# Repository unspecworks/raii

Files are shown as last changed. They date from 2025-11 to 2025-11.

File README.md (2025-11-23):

> [!WARNING]
> work in progress

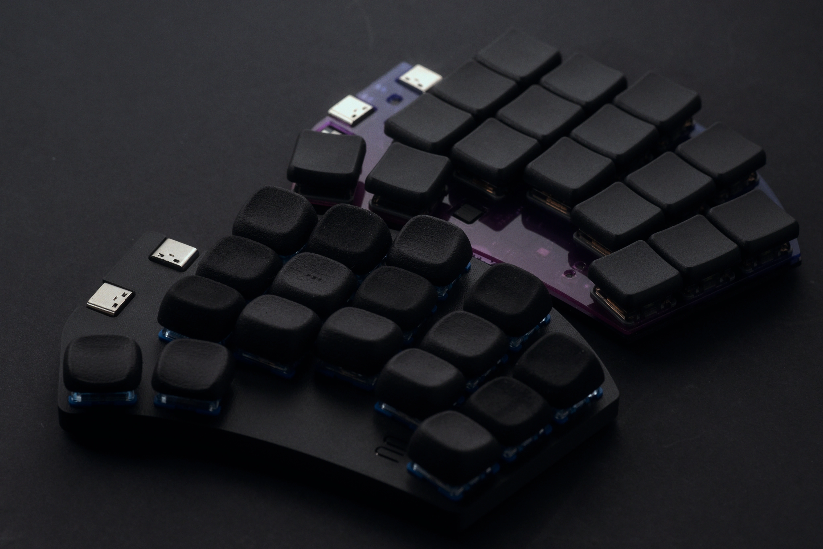
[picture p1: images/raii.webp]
RAII


# RAII

RAII is a customized variant of [waffle87/sweep](https://github.com/waffle87/sweep) featuring splayed columns and various PCB and footprint updates.

## Modifications

* Applied splay to the ring and pinky columns
* Added an additional BOOTSEL button footprint for alternative cases
* Removed the tenting puck mount
* Replaced solder-only switch footprints with Kailh hotswap ONLY sockets
* Added support for Kailh Choc V2
* Added cute ferris

## Links

* [/cases](./cases)
* [/pcb](./pcb)
* [/plate](./plate)
* [firmware](#)

## License

[SOLDERPAD HARDWARE LICENSE VERSION 2.1](./LICENSE)

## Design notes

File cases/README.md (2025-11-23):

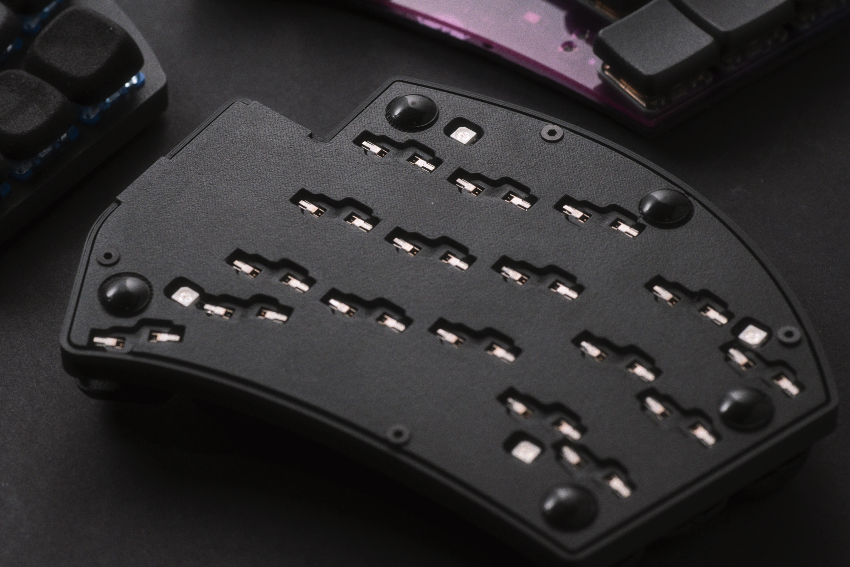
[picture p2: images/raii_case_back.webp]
Plate


# RAII Cases

All case variants use the same bottom case. Make sure to distinguish between the left and right sides.

It has only been tested with FDM printing and was designed specifically with FDM in mind.

## Recommended Version

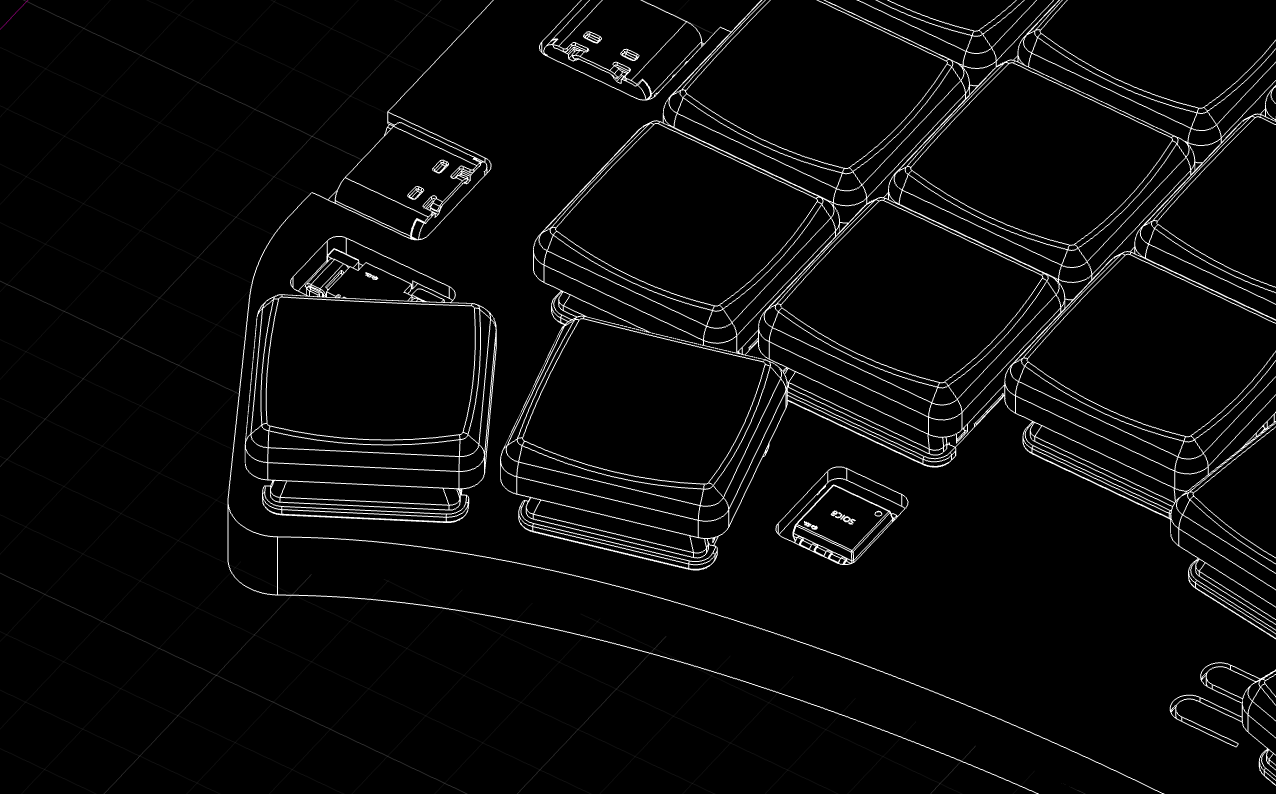
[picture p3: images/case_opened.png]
Opened


All PCB components are placed on the top side, but a few of them sit slightly lower than the height of the Kailh Choc switch plate's top face. Because of this, creating a perfectly enclosed top cover is challenging. Components such as the Flash memory and the display connector may still end up exposed.

- files: `top_left_opened.step` and `top_right_opened.step`

## Fully Enclosed Version

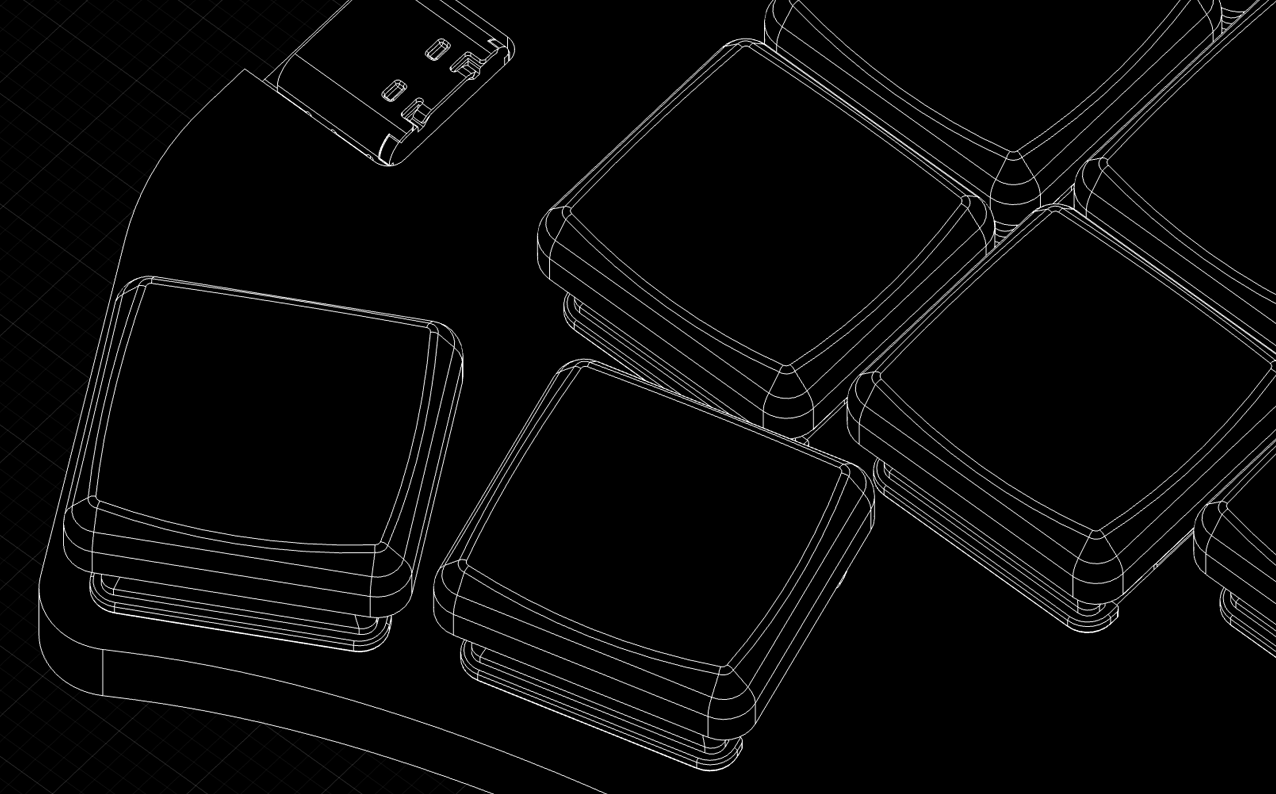
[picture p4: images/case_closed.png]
Closed


This version hides all components (excluding the USB-C receptacle) under a very thin wall. It is optimized for FDM printing.  
Due to the thinness and the nearly contacted height, the cover may bulge during assembly or when removing it from the build plate.

It is recommended to print at least two layers of 0.08 mm.

- files: `top_left_closed.step` and `top_right_closed.step`

## BOM for Assembly

- Rubber feets (≤ 9 mm Diameter), 10 pcs  
- M2 countersunk screws, 5 mm length, 8 pcs  

## Assembly Notes

Insert the switches into the case first, then attach the PCB afterward.  
(Verify switch pin orientation.)  
Attaching the switches and PCB together before inserting them may damage the thin case walls.

This case does not use threaded inserts. Screws are driven directly into the plastic.  
Do not overtighten the screws when assembling the case.

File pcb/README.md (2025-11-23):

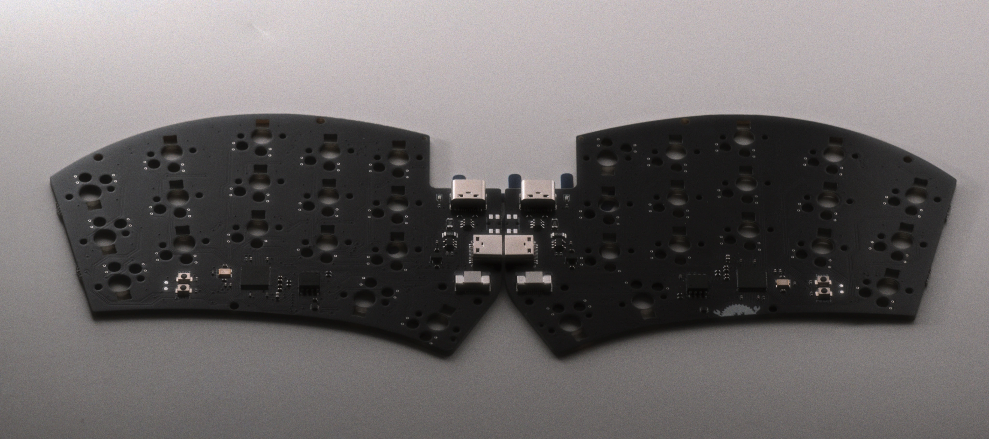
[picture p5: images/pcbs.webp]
PCB


# RAII PCB

## Ordering

TODO

## Hotswap Socket Orientation

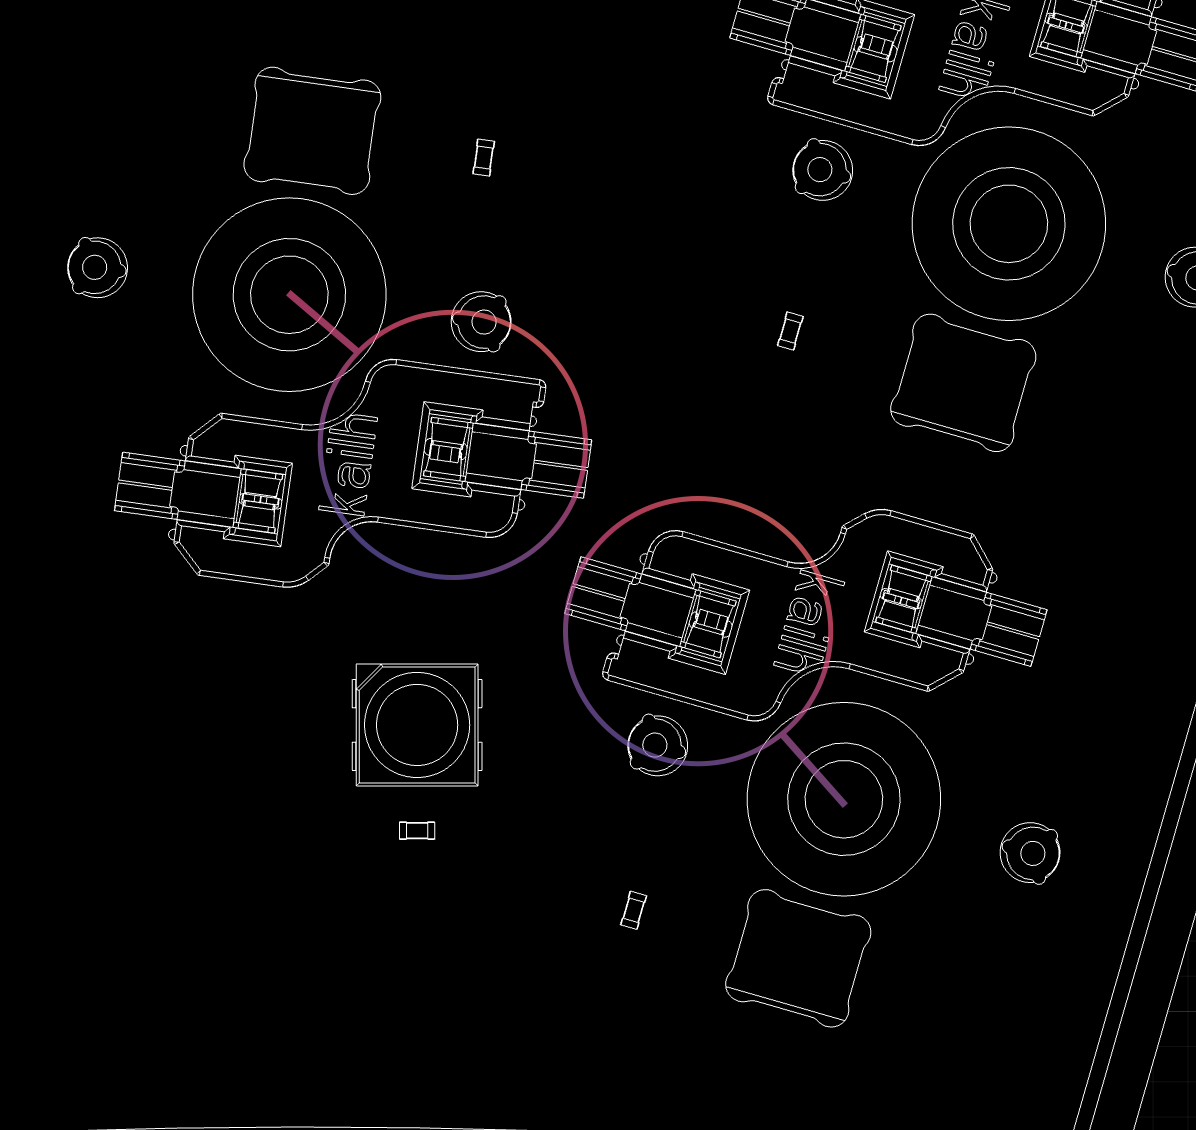
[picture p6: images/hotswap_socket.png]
Socket


If you plan to solder the hotswap sockets yourself, orient the socket so that the rectangular portion faces the center of the switch (the switch center hole).
This orientation is recommended for proper case compatibility.

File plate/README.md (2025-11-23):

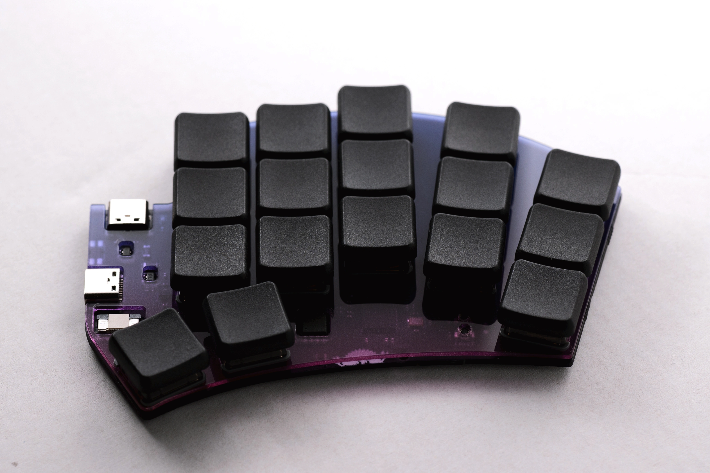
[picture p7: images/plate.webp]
Plate


# RAII Plate

Since this design relies on hotswap sockets, it is recommended to use a plate if you are not using a case.  
There are no standoffs, but the plate should still provide meaningful support.

Because plates are typically intended for flat CNC or laser cutting, some components will inevitably remain exposed.

## Notes

The recommended plate thickness for Choc switches is 1.2 mm.

## Gradient Tint?

Some acrylic fabrication services offer gradient-tinted coloring for cut parts.  
It is difficult to recommend a specific vendor, but platforms like Taobao often have various suppliers that provide this option.

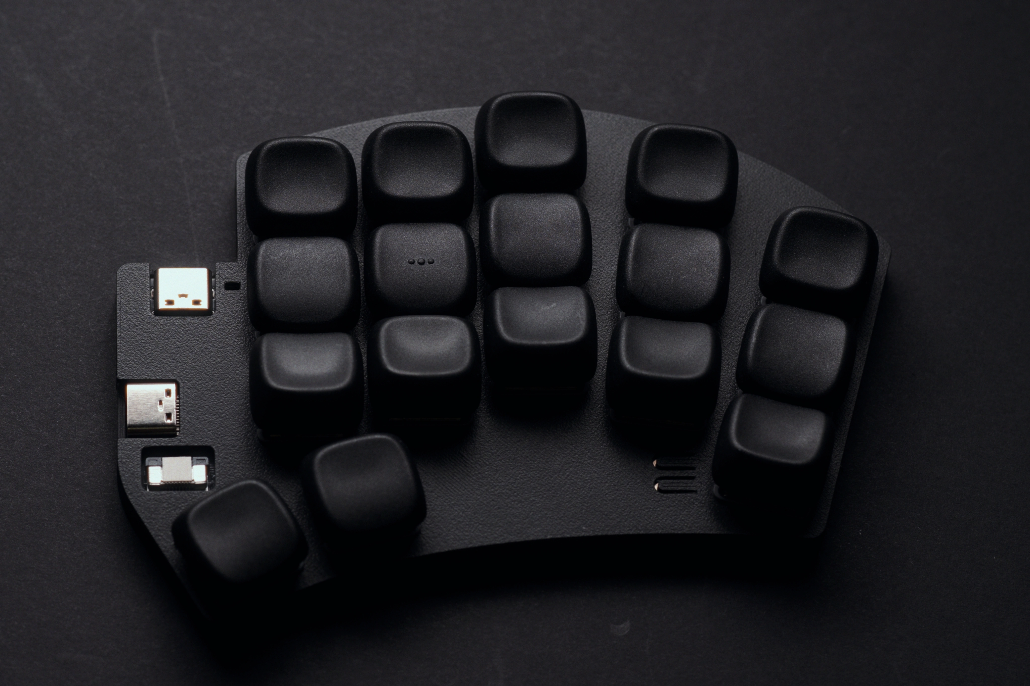
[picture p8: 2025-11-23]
images/f3.webp

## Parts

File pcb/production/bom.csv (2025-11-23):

Designator | Footprint | Quantity | Value | LCSC Part #
C1, C12, C13, C16, C2, C20, C23, C24, C4, C6 | 0402 | 10 | 1u | C52923
C10, C11, C21, C22 | 0402 | 4 | 22p | C1555
C14, C17, C18, C19, C25, C26, C27, C28, C29, C30, C31, C32, C33, C34, C35, C36, C37, C38, C39, C40, C41, C42, C43, C44, C45, C46, C47, C48, C49, C5, C50, C51, C52, C53, C54, C55, C56, C57, C58, C59, C60, C61, C62, C63, C64, C65, C66, C67, C68, C69, C7, C70, C71, C72, C73, C74, C75, C76, C8, C9 | 0402 | 60 | 100n | C1525
C15, C3 | 0603 | 2 | 10u | C19702
D1, D2 | 0603 | 2 | LED | C2286
D10, D3, D4, D5, D6, D7, D8, D9 | LED_WS2812B-Mini_PLCC4_3.5x3.5mm | 8 | WS2812B
F1, F2 | 1206 | 2 | 500mA | C70070
J1, J3, J4, J5 | USB_C_Receptacle_HRO_TYPE-C-31-M-12 | 4 | USB_C_Receptacle_USB2.0_16P | C165948
J6, J8 | TE_0-1734839-8_1x08-1MP_P0.5mm_Horizontal | 2 | Conn_01x08_MountingPin | C5373445
LED1, LED10, LED11, LED12, LED13, LED14, LED15, LED16, LED17, LED18, LED19, LED2, LED20, LED21, LED22, LED23, LED24, LED25, LED26, LED27, LED28, LED29, LED3, LED30, LED31, LED32, LED33, LED34, LED4, LED5, LED6, LED7, LED8, LED9 | LED_choc_6028R | 34 | choc_SK6812MINI-E
R1, R12, R13, R14, R17, R18, R19, R2, R20, R21, R22, R3, R8, R9 | 0402 | 14 | 5.1k | C25905
R10, R11, R4, R5 | 0402 | 4 | 27 | C138021
R15, R16, R6, R7 | 0402 | 4 | 1k | C11702
R23, R26 | 1206 | 2 | 0.005 | C912768
R24, R25, R27, R28 | 0402 | 4 | 75k | C137935
SW1, SW10, SW11, SW12, SW13, SW14, SW15, SW16, SW17, SW18, SW19, SW2, SW20, SW21, SW22, SW23, SW24, SW25, SW26, SW27, SW28, SW29, SW3, SW30, SW31, SW32, SW33, SW34, SW4, SW5, SW6, SW7, SW8, SW9 | Chocv1_sweep | 34 | SW_Push
SW35, SW36, SW37, SW38 | SW_SPST_B3U-1000P | 4 | SW_Pusha | C231329
U1, U5 | QFN-56-1EP_7x7mm_P0.4mm_EP3.2x3.2mm | 2 | RP2040 | C2040
U10, U9 | SOT-563 | 2 | SN74LVC1T45DRL | C352970
U11, U12 | SOT-23-5 | 2 | INA138 | C47914
U2, U7 | SOT-23-3 | 2 | XC6206PxxxMR | C5446
U3, U6 | SOT-23-6-routable | 2 | SRV05-4 | C558418
U4, U8 | SOIC-8_5.23x5.23mm_P1.27mm | 2 | W25Q128JVS | C97521
Y1, Y2 | Crystal_SMD_3225-4Pin_3.2x2.5mm | 2 | Crystal_GND24 | C9002

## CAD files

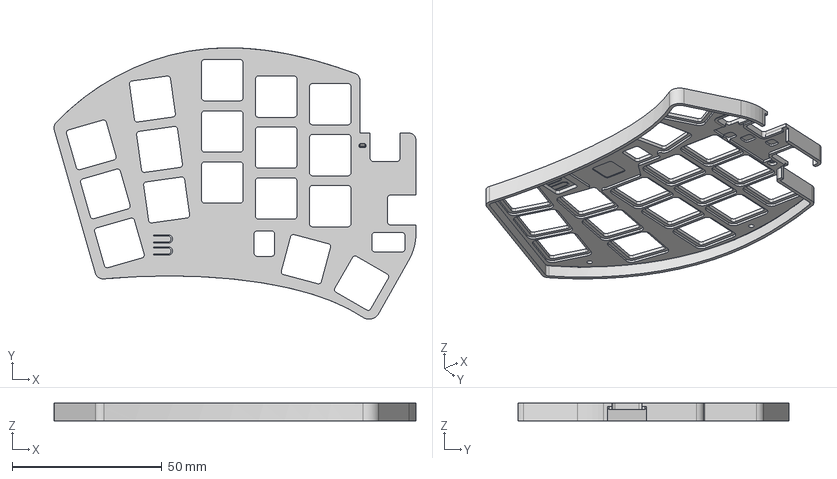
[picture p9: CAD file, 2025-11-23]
cases/top_left_opened.step
120.7 x 90.5 x 5.98 mm

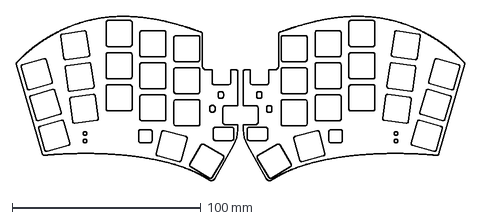
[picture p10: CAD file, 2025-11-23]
plate/PLATE_RAII.dxf
237.7 x 87.1 mm

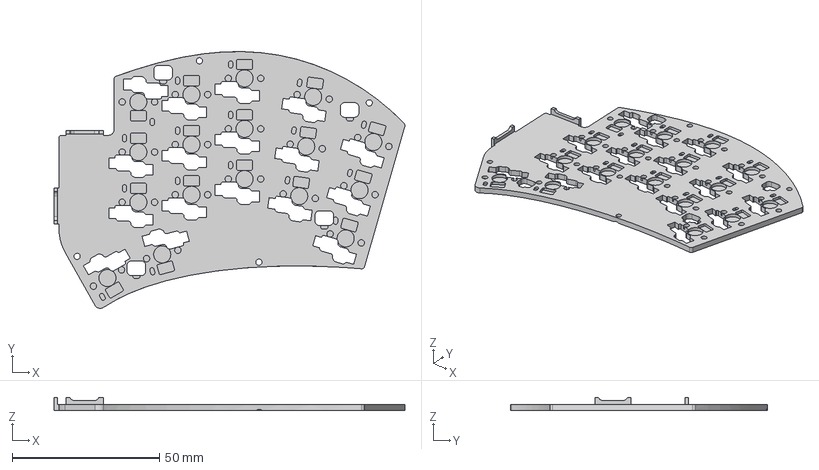
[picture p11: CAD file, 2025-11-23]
cases/bot_right.step
119.0 x 87.1 x 4.48 mm

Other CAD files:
cases/bot_left.step
cases/top_right_closed.step
cases/top_right_opened.step
cases/top_left_closed.step
